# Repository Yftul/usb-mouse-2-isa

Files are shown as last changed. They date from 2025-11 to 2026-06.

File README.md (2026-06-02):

# usb-mouse-2-isa

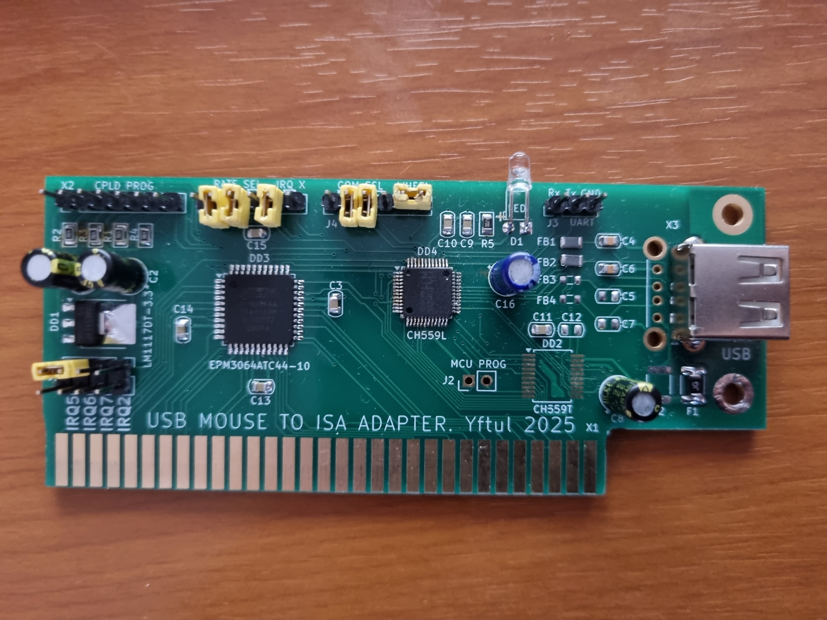
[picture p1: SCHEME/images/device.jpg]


**Проект / Project**
Подключение современной USB-мыши к старым ПК, ожидающим COM мышь.
Connect a modern USB mouse to an old PC expecting a COM mouse.

---

## Описание / Description

Проект `usb-mouse-2-isa` предназначен для реализации поддержки USB-мышей на ретро-компьютерах c ISA шиной.
The `usb-mouse-2-isa` project aims to provide USB mouse support on vintage computers with an ISA bus.

В основе — микроконтроллер и программируемая логика, которая:
At the core are a microcontroller and programmable logic that:

- принимает сигналы от USB-мыши / receive data from a USB mouse;
- преобразует в эмуляцию COM портовой мыши на ISA шине / converts into an emulation of a serial mouse on ISA bus.
- обеспечивает базовую функциональность: движение, нажатие кнопок, прокрутку / provide basic functionality: movement, button clicks, and wheel scrolling.

---

## Общие сведения / General info
Устройство устанавливается в ISA слот. Мышь подключается в USB разъём. При сбросе компьютера, включении и отключении мыши мигает светодиод активности VD1. Также он мигает, если работает драйвер выши и мышь проявляет какую-либо активность.
Перемычками COM SEL J4 можно выбрать COM порт COM1-COM4. При необходимости выбрать нестандартное прерывание, нужно установить перемычку IRQX J5 и выбрать необходимое прерывание IRQ2,5,6,7 установкой перемычки J1. Например:
оставив J4 1-2 3-4 и J5 5-6 без перемычек(open), устройство будет настроена на работу в качестве порта COM1 со стандартными port и IRQ 0x3F8/IRQ3. Если же установить все три перемычки, устройство будет откликаться на стандартный адрес COM4 0x2E8, но из-за установленного IRQX использовать один их IRQ2,5,6,7, выбранный перемычкой J1.
Все комбинации перемычек подписаны на плате.

Кроме того, можно выбрать поддержку колесика мыши, установив перемычку wheel J4 5-6. И уменьшить частоту передачи данных мыши по порту, установив перемычки Rate, где открытым(open) перемычкам соответсвует скорость передачи по умолчанию, устанавливая перемычки, замедляем скорость передачи до 4х раз.

--/

The device is installed into an ISA slot. The mouse is connected to the USB port. When the computer is reset, powered on, or when the mouse is plugged  or unplugged, the activity LED VD1 blinks. It also blinks when the mouse driver is running and the mouse generates any activity.

The COM SEL J4 jumpers allow selecting the COM port number (COM1–COM4). If a non‑standard interrupt is required, you must enable the IRQX jumper J5 and select the desired interrupt (IRQ2, 5, 6, or 7) using jumper J1. Examples:

 - if J4 1–2 and 3–4 are closed, and J5 5–6 is open, the device will be configured as COM1 with the standard port and IRQ (0x3F8 / IRQ3).
 - if all three jumpers are closed, the device will be at the standard COM4 address 0x2E8, but because IRQX is enabled, it will use one of IRQ2, 5, 6, or 7 selected by the jumper J1.

All possible jumpers combinations are written on the PCB.

Additionally, mouse wheel support can be enabled by closing the “wheel” jumper J4 5–6.  
You can also reduce the mouse data rate by configuring the Rate jumpers: the open (default) position corresponds to the normal data rate, and installing the jumpers reduces the rate by up to 4×.

## Структура репозитория / Repository structure

- `MCU/` — исходники микроконтроллера (C/ASM). / microcontroller firmware (C/ASM).
- `CPLD/` — исходники CPLD (VHDL). / CPLD logic design (VHDL).
- `SCHEME/` — схемы подключения, разводка. / schematics, wiring.
- `BIN/` — собранные прошивки. / compiled firmware.
- `README.md` — этот файл. / this README.
- `LICENSE` — лицензия проекта (GPL-3.0). / license file (GPL-3.0).

---

## Требования железа / Hardware requirements

- USB HID-мышь. / USB HID mouse.
- ПК с ISA-шиной и свободными ресурсами для подключения эмулируемого COM порта. / PC with ISA bus and enouth free resources to attach emulated COM port.
- Стандартный драйвер COM мыши / Standard serial mouse driver.

---

## Требования ПО / Software requirements

```bash
# 1. Сборка прошивки микроконтроллера / MCU firmware build
MCU: make clean && make

# 2. Для прошивки используется утилита WCHISPTool и кабель "USB-A - USB-A" / To flash MCU use WCHISPTool and cable "USB-A - USB-A"

# 3. Cинтез и прошивка CPLD / FPGA sinthesis and flash
Quartus 13 or earlier  + Altera byte blaster

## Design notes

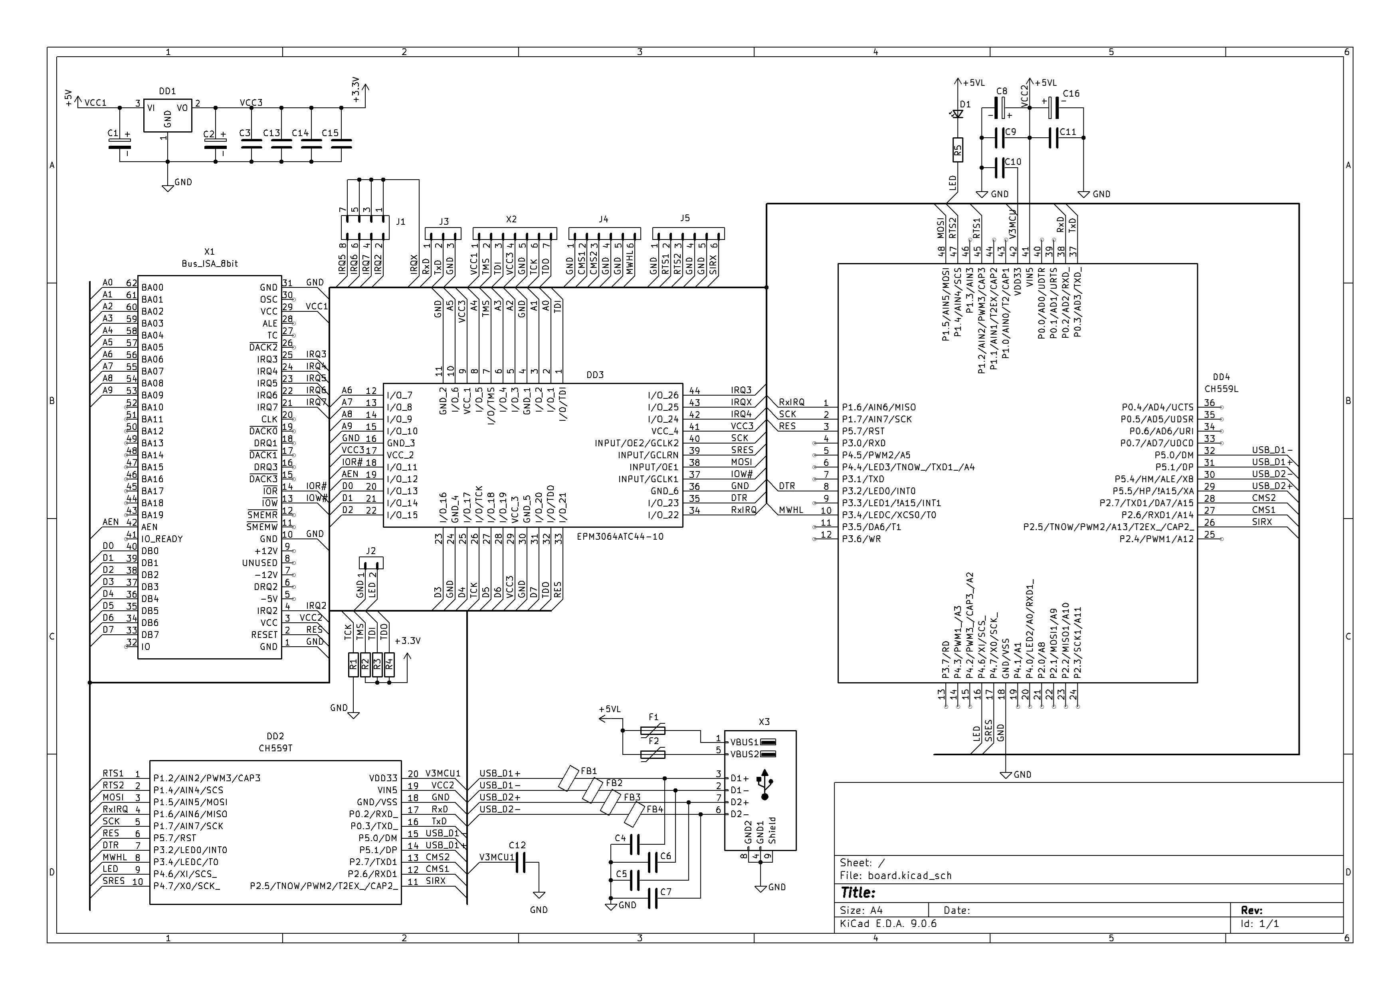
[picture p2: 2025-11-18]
SCHEME/images/scheme.jpg

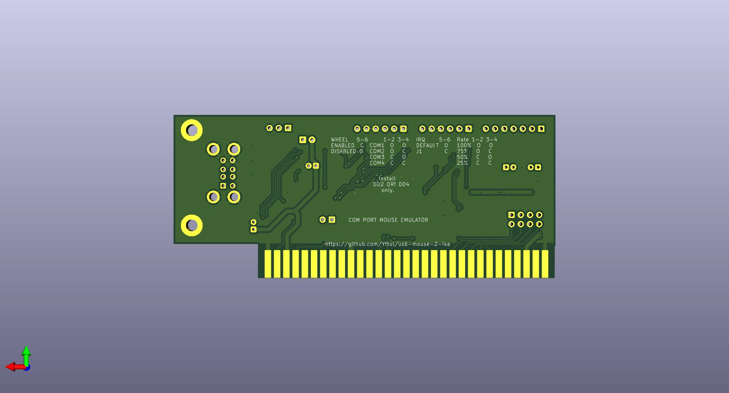
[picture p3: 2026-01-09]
SCHEME/images/board_b.jpg

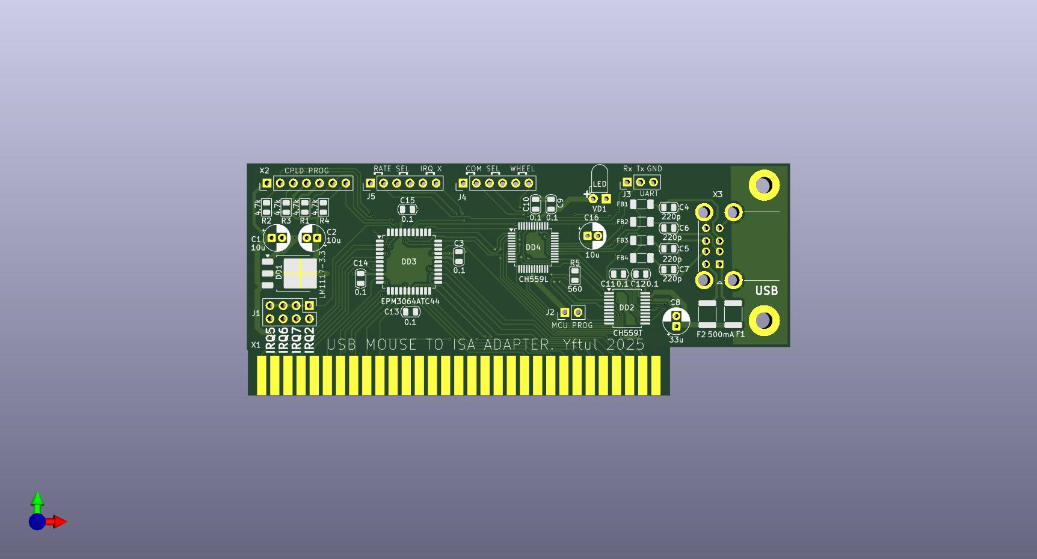
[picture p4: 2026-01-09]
SCHEME/images/board_f.jpg

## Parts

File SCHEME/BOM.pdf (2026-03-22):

Reference | Qty Value | Note
C1,C2,C16 | 3 | 10u | Electrolytic, THT D5.0mm P2.00mm. Can be 10uF to 50uF, 6.3V to 25V
C3,C9,C10,C11,C12,C13,C14,C15 | 8 | 0.1 | Ceramic 0805. Can be 0.068uF to 1uF
C4,C5,C6,C7 | 4 | 220p | Ceramic 0805. Can be 150...470pF
C8 | 1 | 33u | Electrolytic, THT D5.0mm P2.00mm. Can be 33uF to 100uF, 6.3V to 25V
DD1 | 1 | LM1117DT-3.3
DD2 | 1 | CH559T | Install DD2 or DD4 only
DD3 | 1 | EPM3064ATC44 | Can be replaced to ATF1504AS(need to recompile the firmware)
DD4 | 1 | CH559L | Install DD2 or DD4 only
F1 | 1 | 500mA | 1206
F2 | 1 | 500mA | 1206
FB1,FB2,FB3,FB4 | 4 | ~ | 1206 Ferrite bead. Can be replaced with resistor 0..10 Ohm
J1 | 1 | PINHD_2x4_Male
J2 | 1 | PINHD_1x2_Male
J3 | 1 | PINHD_1x3_Male
J4,J5 | 2 | PINHD_1x6_Male
R1,R2,R3,R4 | 4 | 4.7k | 0805. Can be 2…5.1K
R5 | 1 | 560 | 0805. Can be 330…680Ohm
VD1 | 1 | LED | THT 3.0 mm LED
X2 | 1 | PINHD_1x7_Male
X3 | 1 | USB_A_Stacked | Better 2 use single USB

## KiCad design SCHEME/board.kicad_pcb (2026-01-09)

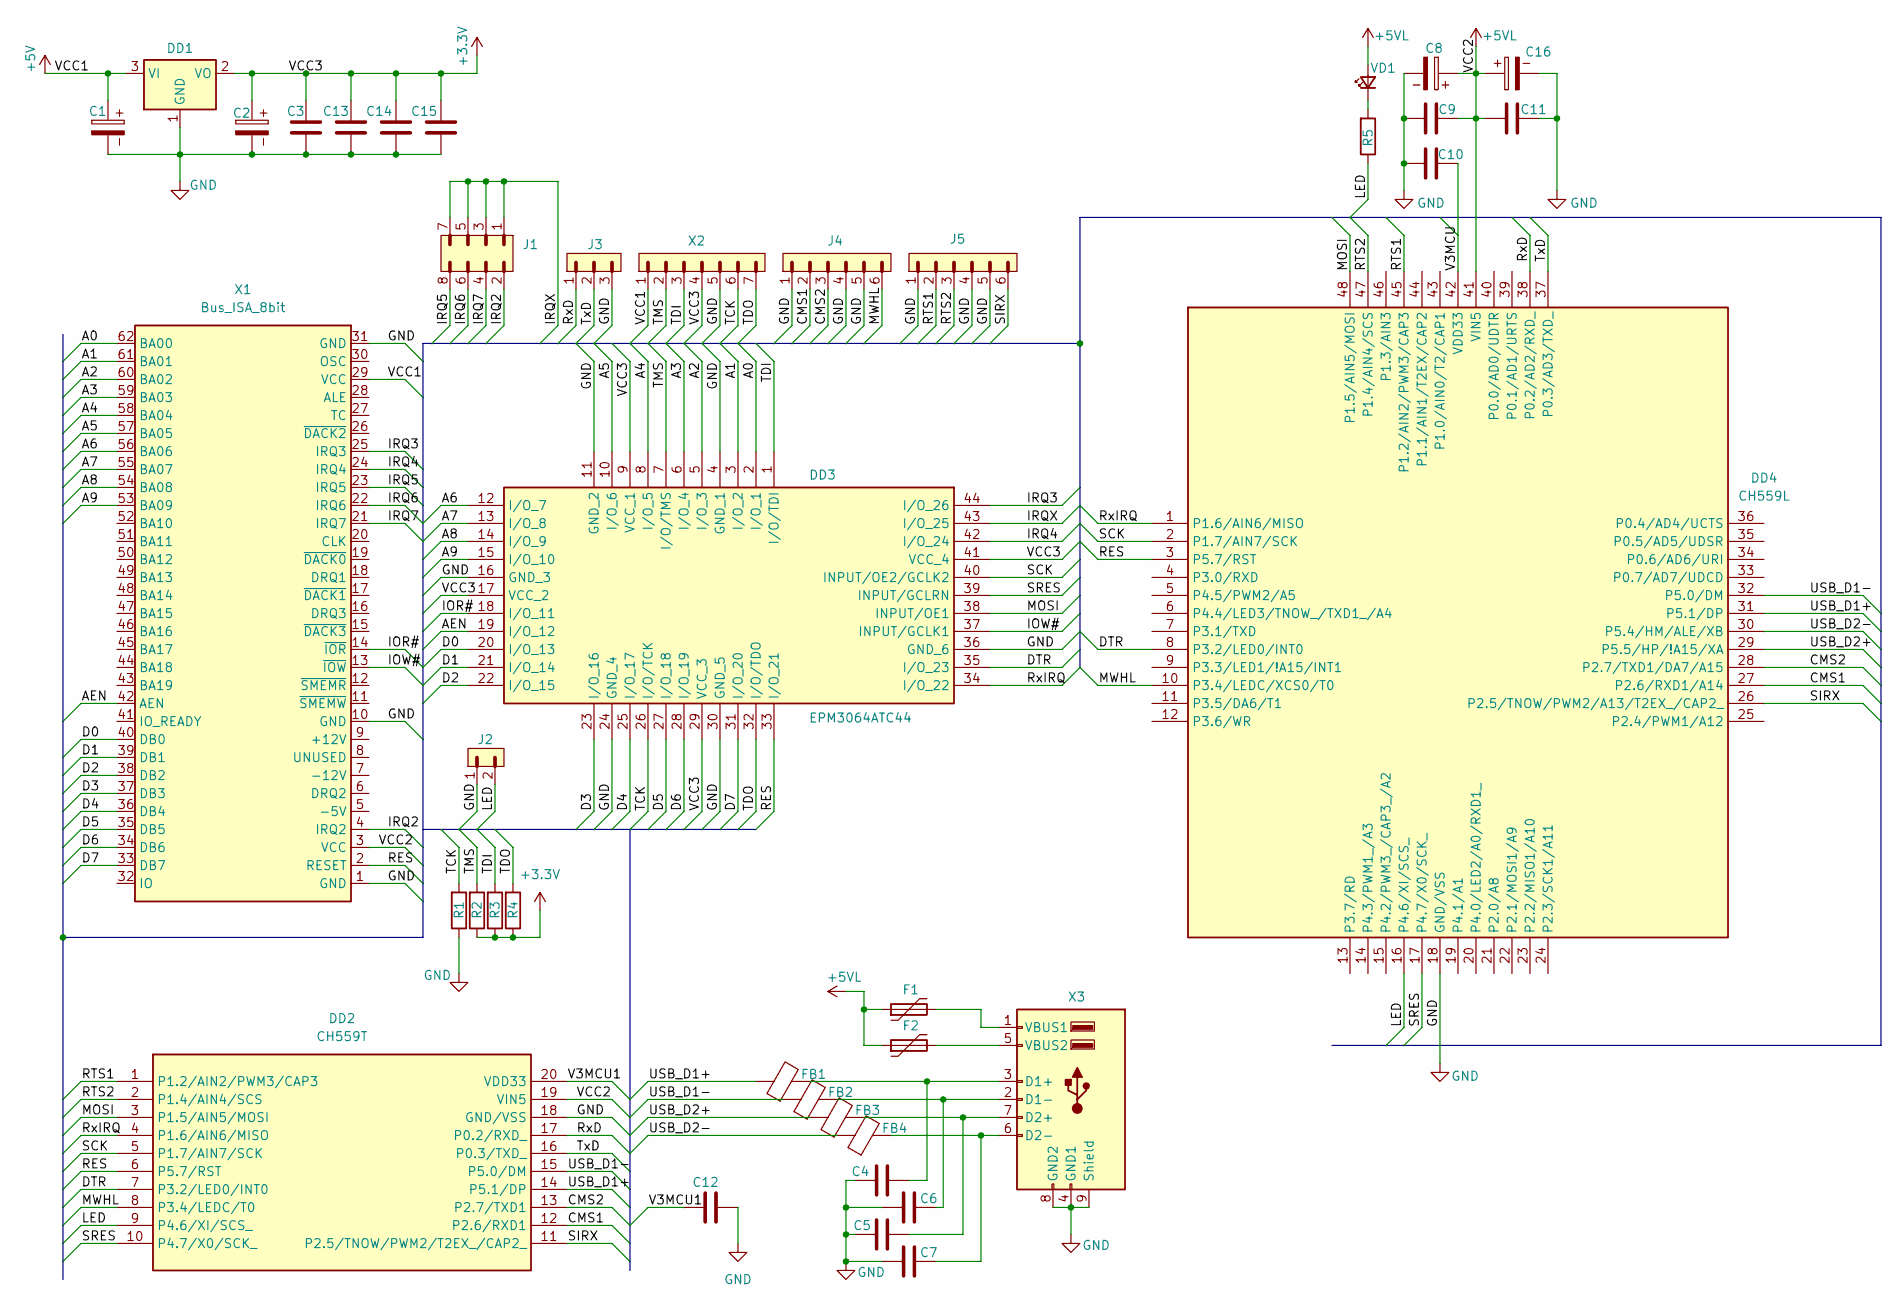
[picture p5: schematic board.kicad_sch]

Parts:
C1, C2, C16: 10u; CP_Radial_D5.0mm_P2.00mm
C3, C9, C10, C11, C12, C13, C14, C15: 0.1; C_0805_2012Metric
C4, C5, C6, C7: 220p; C_0805_2012Metric
C8: 33u; CP_Radial_D5.0mm_P2.00mm
DD1: LM1117DT-3.3; TO-252-3_TabPin2
DD2: CH559T; SSOP-20_5.3x7.2mm_P0.65mm; Manufacturer_Part_Number CH559L
DD3: EPM3064ATC44; TQFP-44_10x10mm_P0.8mm; Manufacturer_Part_Number EPM3032ATC44-4N; Mouser Part Number 989-EPM3032ATC44-4N
DD4: CH559L; LQFP-48_7x7mm_P0.5mm; Manufacturer_Part_Number CH559L
F1: Polyfuse_3A_15V; Fuse_1812_4532Metric; Part Number miniSMDC150F/24; JLCPCB ID C207070
F2: 500mA; Fuse_1812_4532Metric; Part Number miniSMDC150F/24; JLCPCB ID C207070
FB1, FB2, FB3, FB4: L_1206_3216Metric_Pad1.22x1.90mm_HandSolder
J1: PINHD_2x4_Male; PinHeader_2x04_P2.54mm_Vertical
J2: PINHD_1x2_Male; PinHeader_1x02_P2.54mm_Vertical
J3: PINHD_1x3_Male; PinHeader_1x03_P2.54mm_Vertical
J4, J5: PINHD_1x6_Male; PinHeader_1x06_P2.54mm_Vertical
R1, R2, R3, R4: 4.7k; R_0805_2012Metric
R5: 560; R_0805_2012Metric
VD1: LED; LED_D3.0mm_Horizontal_O1.27mm_Z2.0mm
X1: Bus_ISA_8bit; BUS_XT
X2: PINHD_1x7_Male; PinHeader_1x07_P2.54mm_Vertical
X3: USB_A_Stacked; USB_A_CUI_UJ2-ADH-TH_Horizontal_Stacked

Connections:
+3.3V: C2.1, C3.1, C13.1, C14.1, C15.1, DD1.2 (VO), DD3.9 (VCC_1), DD3.17 (VCC_2), DD3.29 (VCC_3), DD3.41 (VCC_4), R2.2, R3.2, R4.2, X2.4
+5V: C1.1, DD1.3 (VI), X1.29 (VCC), X2.1
+5VL: C8.1, C9.2, C11.1, C16.1, DD2.19 (VIN5), DD4.41 (VIN5), F1.1, F2.1, VD1.2 (A), X1.3 (VCC)
/A0: DD3.2 (I/O_1), X1.62 (BA00)
/A1: DD3.3 (I/O_2), X1.61 (BA01)
/A2: DD3.5 (I/O_3), X1.60 (BA02)
/A3: DD3.6 (I/O_4), X1.59 (BA03)
/A4: DD3.8 (I/O_5), X1.58 (BA04)
/A5: DD3.10 (I/O_6), X1.57 (BA05)
/A6: DD3.12 (I/O_7), X1.56 (BA06)
/A7: DD3.13 (I/O_8), X1.55 (BA07)
/A8: DD3.14 (I/O_9), X1.54 (BA08)
/A9: DD3.15 (I/O_10), X1.53 (BA09)
/AEN: DD3.19 (I/O_12), X1.42 (AEN)
/CMS1: DD2.12 (P2.6/RXD1), DD4.27 (P2.6/RXD1/A14), J4.2
/CMS2: DD2.13 (P2.7/TXD1), DD4.28 (P2.7/TXD1/DA7/A15), J4.3
/D0: DD3.20 (I/O_13), X1.40 (DB0)
/D1: DD3.21 (I/O_14), X1.39 (DB1)
/D2: DD3.22 (I/O_15), X1.38 (DB2)
/D3: DD3.23 (I/O_16), X1.37 (DB3)
/D4: DD3.25 (I/O_17), X1.36 (DB4)
/D5: DD3.27 (I/O_18), X1.35 (DB5)
/D6: DD3.28 (I/O_19), X1.34 (DB6)
/D7: DD3.31 (I/O_20), X1.33 (DB7)
/DTR: DD2.7 (P3.2/LED0/INT0), DD3.35 (I/O_23), DD4.8 (P3.2/LED0/INT0)
/IOR#: DD3.18 (I/O_11), X1.14 (~IOR)
/IOW#: DD3.37 (INPUT/GCLK1), X1.13 (~IOW)
/IRQ2: J1.2, X1.4 (IRQ2)
/IRQ3: DD3.44 (I/O_26), X1.25 (IRQ3)
/IRQ4: DD3.42 (I/O_24), X1.24 (IRQ4)
/IRQ5: J1.8, X1.23 (IRQ5)
/IRQ6: J1.6, X1.22 (IRQ6)
/IRQ7: J1.4, X1.21 (IRQ7)
/IRQX: DD3.43 (I/O_25), J1.1, J1.3, J1.5, J1.7
/LED: DD2.9 (P4.6/XI/SCS_), DD4.16 (P4.6/XI/SCS_), J2.2, R5.2
/MOSI: DD2.3 (P1.5/AIN5/MOSI), DD3.38 (INPUT/OE1), DD4.48 (P1.5/AIN5/MOSI)
/MWHL: DD2.8 (P3.4/LEDC/T0), DD4.10 (P3.4/LEDC/XCS0/T0), J4.6
/RES: DD2.6 (P5.7/RST), DD3.33 (I/O_21), DD4.3 (P5.7/RST), X1.2 (RESET)
/RTS1: DD2.1 (P1.2/AIN2/PWM3/CAP3), DD4.45 (P1.2/AIN2/PWM3/CAP3), J5.2
/RTS2: DD2.2 (P1.4/AIN4/SCS), DD4.47 (P1.4/AIN4/SCS), J5.3
/RxD: DD2.17 (P0.2/RXD_), DD4.38 (P0.2/AD2/RXD_), J3.1
/RxIRQ: DD2.4 (P1.6/AIN6/MISO), DD3.34 (I/O_22), DD4.1 (P1.6/AIN6/MISO)
/SCK: DD2.5 (P1.7/AIN7/SCK), DD3.40 (INPUT/OE2/GCLK2), DD4.2 (P1.7/AIN7/SCK)
/SIRX: DD2.11 (P2.5/TNOW/PWM2/T2EX_/CAP2_), DD4.26 (P2.5/TNOW/PWM2/A13/T2EX_/CAP2_), J5.6
/SRES: DD2.10 (P4.7/X0/SCK_), DD3.39 (INPUT/GCLRN), DD4.17 (P4.7/X0/SCK_)
/TCK: DD3.26 (I/O/TCK), R1.1, X2.6
/TDI: DD3.1 (I/O/TDI), R3.1, X2.3
/TDO: DD3.32 (I/O/TDO), R4.1, X2.7
/TMS: DD3.7 (I/O/TMS), R2.1, X2.2
/TxD: DD2.16 (P0.3/TXD_), DD4.37 (P0.3/AD3/TXD_), J3.2
/USB_D1+: DD2.14 (P5.1/DP), DD4.31 (P5.1/DP), FB1.1
/USB_D1-: DD2.15 (P5.0/DM), DD4.32 (P5.0/DM), FB2.1
/USB_D2+: DD4.29 (P5.5/HP/!A15/XA), FB3.1
/USB_D2-: DD4.30 (P5.4/HM/ALE/XB), FB4.1
/V3MCU: C10.2, DD4.42 (VDD33)
/V3MCU1: C12.1, DD2.20 (VDD33)
GND: C1.2, C2.2, C3.2, C4.1, C5.1, C6.1, C7.1, C8.2, C9.1, C10.1, C11.2, C12.2, C13.2, C14.2, C15.2, C16.2, DD1.1 (GND), DD2.18 (GND/VSS), DD3.4 (GND_1), DD3.11 (GND_2), DD3.16 (GND_3), DD3.24 (GND_4), DD3.30 (GND_5), DD3.36 (GND_6), DD4.18 (GND/VSS), J2.1, J3.3, J4.1, J4.4, J4.5, J5.1, J5.4, J5.5, R1.2, X1.1 (GND), X1.10 (GND), X1.31 (GND), X2.5, X3.4 (GND1), X3.8 (GND2), X3.9 (Shield)
unnamed: R5.1, VD1.1 (K)
unnamed: C4.2, FB1.2, X3.3 (D1+)
unnamed: C6.2, FB2.2, X3.2 (D1-)
unnamed: C5.2, FB3.2, X3.7 (D2+)
unnamed: C7.2, FB4.2, X3.6 (D2-)
unnamed: F1.2, X3.1 (VBUS1)
unnamed: F2.2, X3.5 (VBUS2)

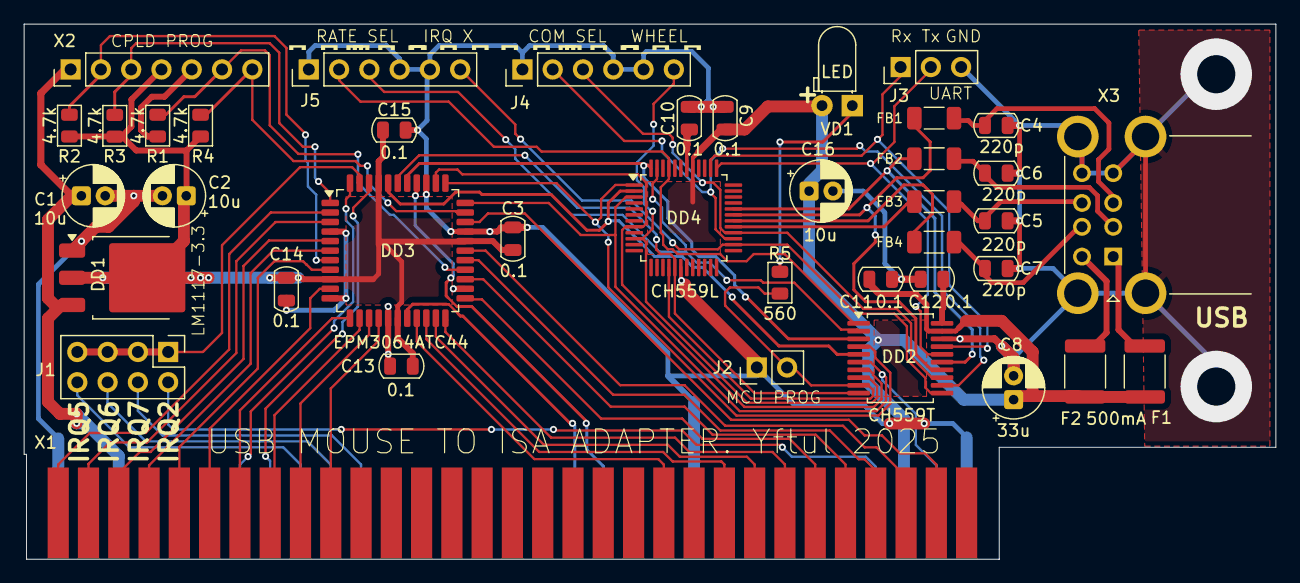
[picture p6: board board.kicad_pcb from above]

Board: 2 copper layers, 105.0 x 44.9 mm, 40 parts (0 on the bottom side), 64 nets.

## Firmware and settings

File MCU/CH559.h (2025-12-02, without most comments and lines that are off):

#define __CH559_H__
typedef unsigned char volatile __xdata    UINT8XV;
typedef unsigned char volatile __pdata    UINT8PV;
#include <compiler.h>
#include <stdint.h>
SFR(PSW,	0xD0);	// program status word
   SBIT(CY,	0xD0, 7);	// carry flag
   SBIT(AC,	0xD0, 6);	// auxiliary carry flag
   SBIT(F0,	0xD0, 5);	// bit addressable general purpose flag 0
   SBIT(RS1,	0xD0, 4);	// register R0-R7 bank selection high bit
   SBIT(RS0,	0xD0, 3);	// register R0-R7 bank selection low bit
#define MASK_PSW_RS       0x18      // bit mask of register R0-R7 bank selection
   SBIT(OV,	0xD0, 2);	// overflow flag
   SBIT(F1,	0xD0, 1);	// bit addressable general purpose flag 1
   SBIT(P,	0xD0, 0);	// ReadOnly: parity flag
SFR(ACC,	0xE0);	// accumulator
SFR(B,	0xF0);	// general purpose register B
SFR(SP,	0x81);	// stack pointer
SFR(DPL,	0x82);	// data pointer low
SFR(DPH,	0x83);	// data pointer high
SFR(SAFE_MOD,	0xA1);	// WriteOnly: writing safe mode
#define CHIP_ID           SAFE_MOD
SFR(GLOBAL_CFG,	0xB1);	// global config, Write@SafeMode
#define bBOOT_LOAD        0x20      // ReadOnly: boot loader status for discriminating BootLoader or Application: set 1 by power on reset, clear 0 by software reset
#define bSW_RESET         0x10      // software reset bit, auto clear by hardware
#define bCODE_WE          0x08      // enable flash-ROM (include code & data area) being program or erasing: 0=writing protect, 1=enable program and erase
#define bDATA_WE          0x04      // enable Data-Flash (flash-ROM data area) being program or erasing: 0=writing protect, 1=enable program and erase
#define bXIR_XSFR         0x02      // force MOVX_@R0/@R1 only for xSFR area: 0=MOVX_@R0/@R1 for standard xdata area inclde xRAM&xBUS&xSFR, 1=MOVX_@R0/@R1 for xSFR only
#define bWDOG_EN          0x01      // enable watch-dog reset if watch-dog timer overflow: 0=as timer only, 1=enable reset if timer overflow
SFR(PCON,	0x87);	// power control and reset flag
#define SMOD              0x80      // baud rate selection for UART0 mode 1/2/3: 0=slow(Fsys/128 @mode2, TF1/32 @mode1/3, no effect for TF2),
#define bRST_FLAG1        0x20      // ReadOnly: recent reset flag high bit
#define bRST_FLAG0        0x10      // ReadOnly: recent reset flag low bit
#define MASK_RST_FLAG     0x30      // ReadOnly: bit mask of recent reset flag
#define RST_FLAG_SW       0x00
#define RST_FLAG_POR      0x10
#define RST_FLAG_WDOG     0x20
#define RST_FLAG_PIN      0x30
#define GF1               0x08      // general purpose flag bit 1
#define GF0               0x04      // general purpose flag bit 0
#define PD                0x02      // power-down enable bit, auto clear by wake-up hardware
SFR(PLL_CFG,	0xB2);	// PLL clock config: lower 5 bits for PLL clock Fpll, upper 3 bits for USB 4x clock Fusb4x, Write@SafeMode
#define MASK_PLL_MULT     0x1F      // bit mask of PLL clock Fpll multiple
#define MASK_USB_4X_DIV   0xE0      // bit mask of USB 4x clock Fusb4x divisor, value 000b means 1000b
SFR(CLOCK_CFG,	0xB3);	// system clock config: lower 5 bits for system clock Fsys, Write@SafeMode
#define bOSC_EN_INT       0x80      // internal oscillator enable and original clock selection: 1=enable & select internal clock, 0=disable & select external clock
#define bOSC_EN_XT        0x40      // external oscillator enable, need quartz crystal or ceramic resonator between X1 and X2 pins
#define bWDOG_IF_TO       0x20      // ReadOnly: watch-dog timer overflow interrupt flag, cleared by reload watch-dog count or auto cleared when MCU enter interrupt routine
#define MASK_SYS_CK_DIV   0x1F      // bit mask of system clock Fsys divisor, value 00000b means 100000b
SFR(SLEEP_CTRL,	0xEA);	// sleep control, Write@SafeMode
#define bSLP_OFF_USB      0x80      // clock off for USB
#define bSLP_OFF_ADC      0x40      // clock off for ADC
#define bSLP_OFF_UART1    0x20      // clock off for UART1
#define bSLP_OFF_P1S1     0x10      // clock off for PWM1 / SPI1
#define bSLP_OFF_SPI0     0x08      // clock off for SPI0
#define bSLP_OFF_TMR3     0x04      // clock off for timer3
#define bSLP_OFF_LED      0x02      // clock off for LED
#define bSLP_OFF_XRAM     0x01      // clock off for xRAM
SFR(WAKE_CTRL,	0xEB);	// wake-up control, Write@SafeMode
#define bWAK_BY_USB       0x80      // enable wake-up by USB event
#define bWAK_RXD1_LO      0x40      // enable wake-up by RXD1 low level
#define bWAK_P1_5_LO      0x20      // enable wake-up by pin P1.5 low level
#define bWAK_P1_4_LO      0x10      // enable wake-up by pin P1.4 low level
#define bWAK_P0_3_LO      0x08      // enable wake-up by pin P0.3 low level
#define bWAK_CAP3_LO      0x04      // enable wake-up by CAP3 low level
#define bWAK_P3_2E_3L     0x02      // enable wake-up by pin P3.2 (INT0) edge or pin P3.3 (INT1) low level
#define bWAK_RXD0_LO      0x01      // enable wake-up by RXD0 low level
SFR(RESET_KEEP,	0xFE);	// value keeper during reset
SFR(WDOG_COUNT,	0xFF);	// watch-dog count, count by clock frequency Fsys/262144
SFR(IE,	0xA8);	// interrupt enable
   SBIT(EA,	0xA8, 7);	// enable global interrupts: 0=disable, 1=enable if E_DIS=0
   SBIT(E_DIS,	0xA8, 6);	// disable global interrupts, intend to inhibit interrupt during some flash-ROM operation: 0=enable if EA=1, 1=disable
   SBIT(ET2,	0xA8, 5);	// enable timer2 interrupt
   SBIT(ES,	0xA8, 4);	// enable UART0 interrupt
   SBIT(ET1,	0xA8, 3);	// enable timer1 interrupt
   SBIT(EX1,	0xA8, 2);	// enable external interrupt INT1
   SBIT(ET0,	0xA8, 1);	// enable timer0 interrupt
   SBIT(EX0,	0xA8, 0);	// enable external interrupt INT0 or LED interrupt
SFR(IP,	0xB8);	// interrupt priority and current priority
   SBIT(PH_FLAG,	0xB8, 7);	// ReadOnly: high level priority action flag
   SBIT(PL_FLAG,	0xB8, 6);	// ReadOnly: low level priority action flag
   SBIT(PT2,	0xB8, 5);	// timer2 interrupt priority level
   SBIT(PS,	0xB8, 4);	// UART0 interrupt priority level
   SBIT(PT1,	0xB8, 3);	// timer1 interrupt priority level
   SBIT(PX1,	0xB8, 2);	// external interrupt INT1 priority level
   SBIT(PT0,	0xB8, 1);	// timer0 interrupt priority level
   SBIT(PX0,	0xB8, 0);	// external interrupt INT0 priority level
SFR(IE_EX,	0xE8);	// extend interrupt enable
   SBIT(IE_WDOG,	0xE8, 7);	// enable watch-dog timer interrupt
   SBIT(IE_GPIO,	0xE8, 6);	// enable GPIO input interrupt
   SBIT(IE_PWM1,	0xE8, 5);	// enable PWM1 interrupt
   SBIT(IE_UART1,	0xE8, 4);	// enable UART1 interrupt
   SBIT(IE_ADC,	0xE8, 3);	// enable ADC interrupt
   SBIT(IE_USB,	0xE8, 2);	// enable USB interrupt
   SBIT(IE_TMR3,	0xE8, 1);	// enable timer3 interrupt
   SBIT(IE_SPI0,	0xE8, 0);	// enable SPI0 interrupt
SFR(IP_EX,	0xE9);	// extend interrupt priority
#define bIP_LEVEL         0x80      // ReadOnly: current interrupt nested level: 0=no interrupt or two levels, 1=one level
#define bIP_GPIO          0x40      // GPIO input interrupt priority level
#define bIP_PWM1          0x20      // PWM1 interrupt priority level
#define bIP_UART1         0x10      // UART1 interrupt priority level
#define bIP_ADC           0x08      // ADC interrupt priority level
#define bIP_USB           0x04      // USB interrupt priority level
#define bIP_TMR3          0x02      // timer3 interrupt priority level
#define bIP_SPI0          0x01      // SPI0 interrupt priority level
SFR(GPIO_IE,	0xCF);	// GPIO interrupt enable
#define bIE_IO_EDGE       0x80      // enable GPIO edge interrupt: 0=low/high level, 1=falling/rising edge
#define bIE_RXD1_LO       0x40      // enable interrupt by RXD1 low level / falling edge
#define bIE_P5_5_HI       0x20      // enable interrupt by pin P5.5 high level / rising edge
#define bIE_P1_4_LO       0x10      // enable interrupt by pin P1.4 low level / falling edge
#define bIE_P0_3_LO       0x08      // enable interrupt by pin P0.3 low level / falling edge
#define bIE_P5_7_HI       0x04      // enable interrupt by pin P5.7 (RST) high level / rising edge
#define bIE_P4_1_LO       0x02      // enable interrupt by pin P4.1 low level / falling edge
#define bIE_RXD0_LO       0x01      // enable interrupt by RXD0 low level / falling edge
SFR16(ROM_ADDR,	0x84);	// address for flash-ROM, little-endian
SFR(ROM_ADDR_L,	0x84);	// address low byte for flash-ROM
SFR(ROM_ADDR_H,	0x85);	// address high byte for flash-ROM
SFR16(ROM_DATA,	0x8E);	// data for flash-ROM writing, little-endian
SFR(ROM_DATA_L,	0x8E);	// data low byte for flash-ROM writing
SFR(ROM_DATA_H,	0x8F);	// data high byte for flash-ROM writing
SFR(ROM_CTRL,	0x86);	// WriteOnly: flash-ROM control
#define ROM_CMD_PROG      0x9A      // WriteOnly: flash-ROM word program operation command, for changing some ROM bit of a word from 1 to 0
#define ROM_CMD_ERASE     0xA6      // WriteOnly: flash-ROM sector erase operation command, for changing all ROM bit of 1KBytes from 0 to 1
#define ROM_STATUS        ROM_CTRL
#define bROM_ADDR_OK      0x40      // ReadOnly: flash-ROM operation address valid flag, can be reviewed before or after operation: 0=invalid parameter, 1=address valid
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

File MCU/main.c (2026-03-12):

/******************************************************************************
 * Project : USB-to-ISA Mouse Adapter — Replica
 * File    : main.c
 * Author  : Pyshchev Alexander aka Yftul
 * License : GPL-3.0
 *
 * Description :
 *     Firmware module for microcontroller side of USB-to-ISA adapter.
 *     Handles USB mouse communication, event parsing, buffering, and
 *     translation into ISA bus signals understood by legacy hardware.
 *
 * Notes :
 *     - Designed for embedded 8-bit MCU (e.g., ch559).
 *     - Uses hardware USB host and simple state machine for
 *       compatibility and low latency.
 ******************************************************************************/
#include <stdbool.h>
#include <stdint.h>
#include <stdio.h>
#include <string.h>
#include "CH559.h"
#include "util.h"
#include "USBHost.h"

//===========================================================================
// Общие определения и константы
//===========================================================================
// Не работает UART по прерыванию
// ToDo: починить
#define UART_fixed 0

#pragma disable_warning 126 /* Убирает назойливое предупреждение о недоступном коде */
                            /* связанном с передачей констант в SPI_SEND_PACKET */

#define UART_BAUDRATE  115200UL

#define MS_RX_BUF_SIZE 16      /* Размер приёмного буфера событй hid устройства,
                                * реально используется 4 байта
                                */
#define SPI_TX_BUFFER_SIZE 255 /* Размер буфера передачи SPI */
#define UART_TX_BUF_SIZE   128 /* Размер буфера передачи UART */
#define UART_TX_MASK       (UART_TX_BUF_SIZE - 1)

#define UART_RX_BUF_SIZE   16 /* Размер буфера приёма UART */
#define UART_RX_MASK       (UART_RX_BUF_SIZE - 1)

#define TIMER0_CONST (65536-4000) /* Период вызова прерывания 1 мс */
#define LED_CONST (64000) /* Длительность послесвечения светодиода (16 мс) */
#define TIMER2_RELOAD_FAST   (65536 - 100) /* Период вызова прерывания 25 мкс */
#define TIMER2_RELOAD_SLOW   (65536 - 400) /* Период вызова прерывания 100 мкс */

#define CRITICAL_SECTION(code_block) \
    do { \
        uint8_t _ea_state = EA; \
        EA = 0; \
        code_block \
        EA = _ea_state; \
    } while(0)

#define GLUE(a, b)      a##b
#define GLUE3(a, b, c)  a##b##c
#define _BV(bit)        (1U << (bit))

typedef enum {
    SELECT_COM1 = 0,
    SELECT_COM2 = 1,
    SELECT_COM3 = 2,
    SELECT_COM4 = 3,
} com_select_t;

typedef enum {
    PS2_SAMPLES_PER_SEC_10 = 10,
    PS2_SAMPLES_PER_SEC_20 = 20,
    PS2_SAMPLES_PER_SEC_40 = 40,
    PS2_SAMPLES_PER_SEC_60 = 60,
    PS2_SAMPLES_PER_SEC_80 = 80,
    PS2_SAMPLES_PER_SEC_100 = 100,
    PS2_SAMPLES_PER_SEC_200 = 200,
} data_rate_t;

#define PS2_SAMPLES_PER_SEC_UFAST   PS2_SAMPLES_PER_SEC_100
#define PS2_SAMPLES_PER_SEC_FAST    PS2_SAMPLES_PER_SEC_80
#define PS2_SAMPLES_PER_SEC_MID     PS2_SAMPLES_PER_SEC_40
#define PS2_SAMPLES_PER_SEC_SLOW    PS2_SAMPLES_PER_SEC_20

//===========================================================================
// Примитивы для работы с портами ch559
//===========================================================================
enum pin_mode {
    PIN_MODE_INPUT = 0,
    PIN_MODE_INPUT_PULLUP = 1,
    PIN_MODE_OUTPUT = 2,
    PIN_MODE_OUTPUT_OPEN_DRAIN = 3,
    PIN_MODE_OUTPUT_OPEN_DRAIN_2CLK = 4,
    PIN_MODE_INPUT_OUTPUT_PULLUP = 5,
    PIN_MODE_INPUT_OUTPUT_PULLUP_2CLK = 6,
};

#define _PORT_IN_P0   P0
#define _PORT_IN_P1   P1
#define _PORT_IN_P2   P2
#define _PORT_IN_P3   P3
#define _PORT_IN_P4   P4_IN
#define _PORT_IN_P5   P5

#define _PORT_OUT_P0   P0
#define _PORT_OUT_P1   P1
#define _PORT_OUT_P2   P2
#define _PORT_OUT_P3   P3
#define _PORT_OUT_P4   P4_OUT
#define _PORT_OUT_P5   P5

#define _PORT_OC_P0   _OC
#define _PORT_OC_P1   _OC
#define _PORT_OC_P2   _OC
#define _PORT_OC_P3   _OC

#ifndef bP4_OC
#define bP4_OC 0
#endif

#define PORT_OUT(x)    GLUE(_PORT_OUT_, x) /* ожидаем: P1 -> P1, P4 - > P4_OUT */
#define PORT_IN(x)     GLUE(_PORT_IN_, x)  /* ожидаем: P1 -> P1, P4 - > P4_IN */
#define PORT_DIR(x)    GLUE(x, _DIR)  /* ожидаем: P1 -> P1_DIR */
#define PORT_PU(x)     GLUE(x, _PU) /* ожидаем: P1 -> P1_PU, P4 - > P4_PU */
#define PORT_OC(x)     GLUE3(b, x, _OC)  /* ожидаем: P1 -> bP1_OC, bP4 -> bP4_OC */

#define pinMode(port, pin, mode)\
do {\
    if ((mode) == PIN_MODE_INPUT) {\
        PORT_CFG &= ~PORT_OC(port);\
        PORT_DIR(port) &= ~(1 << (pin));\
        PORT_PU(port) &= ~(1 << (pin));\
    } else if ((mode) == PIN_MODE_INPUT_PULLUP) {\
        PORT_CFG &= ~PORT_OC(port);\
        PORT_DIR(port) &= ~(1 << (pin));\
        PORT_PU(port) |=  (1 << (pin));\
    } else if ((mode) == PIN_MODE_OUTPUT) {\
        PORT_CFG &= ~PORT_OC(port);\
        PORT_DIR(port) |=  (1 << (pin));\
        /*PORT_PU(port) not used*/\
    } else if ((mode) == PIN_MODE_OUTPUT_OPEN_DRAIN) {\
        PORT_CFG |= PORT_OC(port);\
        PORT_DIR(port) &= ~(1 << (pin));\
        PORT_PU(port) &= ~(1 << (pin));\
    } else if ((mode) == PIN_MODE_OUTPUT_OPEN_DRAIN_2CLK) {\
        PORT_CFG |= PORT_OC(port);\
        PORT_DIR(port) |=  (1 << (pin));\
        PORT_PU(port) &= ~(1 << (pin));\
    } else if ((mode) == PIN_MODE_INPUT_OUTPUT_PULLUP) {\
        PORT_CFG |= PORT_OC(port);\
        PORT_DIR(port) &= ~(1 << (pin));\
        PORT_PU(port) |=  (1 << (pin));\
    } else if ((mode) == PIN_MODE_INPUT_OUTPUT_PULLUP_2CLK) {\
        PORT_CFG |= PORT_OC(port);\
        PORT_DIR(port) |=  (1 << (pin));\
        PORT_PU(port) |=  (1 << (pin));\
    }\
} while (0)

//===========================================================================
// Определение функционала ножек процессора.
//===========================================================================
#define SPI_RESOUT_PORT   P4 /* P4.7 HW RESET */
#define SPI_RESOUT_PIN    7
#define SPI_MOSI_PORT     P1 /* P1.5 HW MOSI */
#define SPI_MOSI_PIN      5
#define SPI_SCK_PORT      P1 /* P1.7 HW SCK */
#define SPI_SCK_PIN       7

#define DTR_PORT          P3 /* P3.2 INT0 */
#define DTR_PIN           2

#if USE_DEVBOARD
#define LED_PORT          P1
#define LED_PIN           4
#else
#define LED_PORT          P4 /* Один вывод с PRG */
#define LED_PIN           6
#endif

#define PRG_PORT          P4
#define PRG_PIN           6

#define COM_SEL1_PORT     P2
#define COM_SEL1_PIN      6
#define COM_SEL2_PORT     P2
#define COM_SEL2_PIN      7

#define WHEEL_SEL_PORT    P3
#define WHEEL_SEL_PIN     4

#define IRQX_SEL_PORT     P2
#define IRQX_SEL_PIN      5

#define RATE_SEL1_PORT    P1
#define RATE_SEL1_PIN     2
#define RATE_SEL2_PORT    P1
#define RATE_SEL2_PIN     4

#define RxIRQ_PORT        P1
#define RxIRQ_PIN         6

#define USE_IRQ3          0
#define USE_IRQX          1
#define USE_IRQ4          2

#define RxD_PORT          P0
#define RxD_PIN           2
#define TxD_PORT          P0
#define TxD_PIN           3

//===========================================================================
// Данные от CPLD
//===========================================================================
// 1 - не готовность приема символа, 0 - готовность
#if USE_DEVBOARD // Не ждём подтверждения приема
#define not_rdy_2rcv() (0)
#else
#define not_rdy_2rcv() (PORT_IN(RxIRQ_PORT) & _BV(RxIRQ_PIN))
#endif

#define get_mouse_power_state() (PORT_IN(DTR_PORT) & _BV(DTR_PIN))

//===========================================================================
// Программый SPI для связи с CPLD
//===========================================================================
#define spi_mosi_high()    (PORT_OUT(SPI_MOSI_PORT) |= _BV(SPI_MOSI_PIN))
#define spi_mosi_low()     (PORT_OUT(SPI_MOSI_PORT) &= ~_BV(SPI_MOSI_PIN))
#define spi_sck_high()     (PORT_OUT(SPI_SCK_PORT) |= _BV(SPI_SCK_PIN))
#define spi_sck_low()      (PORT_OUT(SPI_SCK_PORT) &= ~_BV(SPI_SCK_PIN))
#define spi_reset_high()   (PORT_OUT(SPI_RESOUT_PORT) |= _BV(SPI_RESOUT_PIN))
#define spi_reset_low()    (PORT_OUT(SPI_RESOUT_PORT) &= ~_BV(SPI_RESOUT_PIN))

#define spi_timer_stop()  do { TR2 = 0; } while(0)

#define spi_timer_fast()  do { \
    TR2 = 0; \
    RCAP2H = (uint8_t)((TIMER2_RELOAD_FAST >> 8) & 0xFF); \
    RCAP2L = (uint8_t)(TIMER2_RELOAD_FAST & 0xFF); \
    TH2 = RCAP2H; TL2 = RCAP2L; \
    TR2 = 1; \
} while(0)

#define spi_timer_slow()  do { \
    TR2 = 0; \
    RCAP2H = (uint8_t)((TIMER2_RELOAD_SLOW >> 8) & 0xFF); \
    RCAP2L = (uint8_t)(TIMER2_RELOAD_SLOW & 0xFF); \
    TH2 = RCAP2H; TL2 = RCAP2L; \
    TR2 = 1; \
} while(0)

#define SPI_DELAY() do { __asm__("nop"); __asm__("nop"); \
    __asm__("nop"); __asm__("nop"); } while(0)

#define SPI_SEND_BIT(bit_mask, tx_data) do { \
    spi_sck_low(); \
    SPI_DELAY(); \
    if ((tx_data) & (bit_mask)) spi_mosi_high(); else spi_mosi_low(); \
    SPI_DELAY(); \
    spi_sck_high(); \
    SPI_DELAY(); \
} while (0)

// Пакет из 7 бит с данными мыши
#define SPI_SEND_PACKET(tx_data) do { \
    SPI_SEND_BIT(0x40, (tx_data)); \
    SPI_SEND_BIT(0x20, (tx_data)); \
    SPI_SEND_BIT(0x10, (tx_data)); \
    SPI_SEND_BIT(0x08, (tx_data)); \
    SPI_SEND_BIT(0x04, (tx_data)); \
    SPI_SEND_BIT(0x02, (tx_data)); \
    SPI_SEND_BIT(0x01, (tx_data)); \
    spi_sck_low(); \
    spi_mosi_low(); \
} while (0)

#define SPI_RESET() do { spi_reset_high(); spi_reset_low(); } while(0)

//===========================================================================
// Светодиод
//===========================================================================
#if USE_DEVBOARD
#define led_on()        (PORT_OUT(LED_PORT) |= _BV(LED_PIN))
#define led_off()       (PORT_OUT(LED_PORT) &= ~_BV(LED_PIN))
#else
#define led_on()        (PORT_OUT(LED_PORT) &= ~_BV(LED_PIN))
#define led_off()       (PORT_OUT(LED_PORT) |= _BV(LED_PIN))
#endif

#define led_timer_stop()  do { T3_CTRL &= ~bT3_CNT_EN; } while(0)
#define led_timer_start() do { T3_CTRL |= bT3_CNT_EN; } while(0)

//===========================================================================
// Декларации функций
//===========================================================================
static inline void spi_send_config(uint8_t opt_com, uint8_t opt_irq);
extern FunctionReference runBootloader;

//===========================================================================
// Глобальные переменные
//===========================================================================
static uint8_t opt_com_settings;
static uint8_t opt_wheel_enabled;
static uint8_t opt_rate_settings;
static uint8_t opt_irq_settings;

static volatile uint8_t m_wheel;

static volatile uint8_t spi_tx_buf[SPI_TX_BUFFER_SIZE];
static volatile uint8_t spi_tx_buf_w;
static volatile uint8_t spi_tx_buf_r;
static volatile uint8_t spi_tx_buf_count;

static volatile uint8_t uart_tx_buf[UART_TX_BUF_SIZE];
static volatile uint8_t uart_tx_r;
static volatile uint8_t uart_tx_w;

static volatile uint8_t uart_rx_buf[UART_RX_BUF_SIZE];
static volatile uint8_t uart_rx_r;
static volatile uint8_t uart_rx_w;
static volatile uint8_t uart_rx_buf_count;

static volatile uint8_t mouse_start;      // Необходимо вывести приветствие мыши
static volatile uint8_t mouse_enabled;    // Мышь активна
static volatile uint8_t device_init;      // Произведена инициализация адресов/IRQ устройства
static volatile uint8_t allow_send_data;  // Флаг синхронизации передачи данных
static volatile uint8_t fatal_error;
static volatile uint8_t timer0_limit;

//===========================================================================
// Общие функции
//===========================================================================
// Отправить MCU в сон
static inline void mcu_sleep(void)
{
    // Не работает, вызывает проблемы со SPI
    // PCON |= PD;  // Power down mode
}

//===========================================================================
// Ограничение переменной значениями [min, max]
static inline int8_t clamp8(int16_t val, int8_t min, int8_t max)
{
    if (val < (int16_t)min) return min;
    if (val > (int16_t)max) return max;
    return (int8_t)val;
}

static inline int16_t clamp16(int32_t val, int16_t min, int16_t max)
{
    if (val < (int32_t)min) return min;
    if (val > (int32_t)max) return max;
    return (int16_t)val;
}

//===========================================================================
// Прерывания
//===========================================================================
// Выключилась линия RTS
static void int0_isr(void) __interrupt (INT_NO_INT0)
{
    mouse_enabled = get_mouse_power_state();
}

// Задается частота вывода сигнала мыши
static void timer0_isr(void) __interrupt (INT_NO_TMR0)
{
    static uint8_t cnt = 0;

    if (++cnt >= timer0_limit) {
        cnt = 0;
        allow_send_data = true;
    }
}

// Управление послесвечением светодиода
static void Timer3_ISR(void) __interrupt (INT_NO_TMR3)
{
    T3_STAT |= bT3_IF_END;
    led_off();
    led_timer_stop();
}

// Передача данных мыши в CPLD
static void Timer2_ISR(void) __interrupt (INT_NO_TMR2)
{
    uint8_t current_byte;
    TF2 = 0; // Не сбрасывается автоматически

    // Проверяем возможность передачи
    if (not_rdy_2rcv() && device_init) {
        // Медленно продолжаем проверять возможность передачи
        spi_timer_slow();
        return;
    }

    // Нечего передавать, останавливаемся
    if (!spi_tx_buf_count) {
        spi_timer_stop();
        return;
    }

    device_init = true;

    // Забираем байт из буфера
    current_byte = spi_tx_buf[spi_tx_buf_r];
    if (++spi_tx_buf_r == SPI_TX_BUFFER_SIZE) {
        spi_tx_buf_r = 0;
    }
    spi_tx_buf_count--;

    // Линейная передача без циклов
    SPI_SEND_PACKET(current_byte);

    // Управление таймером
    if (!spi_tx_buf_count) { // Нечего передавать, останавливаемся
        spi_timer_stop();
    } else {                 // Продолжаем передавать
        spi_timer_fast();
    }
}

// Обработка событий UART
static void uart_isr(void) __interrupt (INT_NO_UART0)
{
    uint8_t next;
    if (TI) {
        TI = 0;
        next = (uart_tx_r + 1) & UART_TX_MASK;
        if (next != uart_tx_w) {
            SBUF = uart_tx_buf[uart_tx_r];
            uart_tx_r = next;
        }
    }

    if (RI) {
        RI = 0;
        if (uart_rx_buf_count < UART_RX_BUF_SIZE) {
            uart_rx_buf[uart_rx_w] = SBUF;
            uart_rx_w = (uart_rx_w + 1) & UART_RX_MASK;
            uart_rx_buf_count++;
        }
    }
}

//===========================================================================
// Принимаем команды из UART
//===========================================================================
// putchar используется функцией printf
#if UART_fixed
int putchar(int c)
{
    uint8_t next;
    CRITICAL_SECTION(
        next = (uart_tx_w + 1) & UART_TX_MASK;
        if (next == uart_tx_r) { // Переполнение
            return -1;
        }

        uart_tx_buf[uart_tx_w] = c & 0xFF;
        if (uart_tx_w == uart_tx_r) {
            TI = 1;
        }
        uart_tx_w = next;
    );
    return c;
}
#else
int putchar(int c)
{
    while(!TI) ;
    TI = 0;
    SBUF = c & 0xFF;
    return c;
}
#endif
#if UART_fixed
// getchar может использоваться функцией scanf
int getchar(void)
{
    uint8_t c = 0;
    CRITICAL_SECTION(
        if (uart_rx_buf_count) {
            c = uart_rx_buf[uart_rx_r];
            uart_rx_r = (uart_rx_r + 1) & UART_RX_MASK;
            uart_rx_buf_count--;
        }
    );
    return c;
}
#else
int getchar(void)
{
    while(!RI) ;
    RI = 0;
    return SBUF;
}
#endif

// Переход в режим программирования(аналог замыканию пинов)
void processUart(void)
{
#if UART_fixed
    while(uart_rx_buf_count > 2) {
        if (getchar() == '~')
            if (getchar() == '~')
                if (getchar() == '~')
                    runBootloader();
    }
#endif
}

//===========================================================================
// Управление светодиодом
//===========================================================================
// Мигнуть светодиодом
void flash_led(void)
{
    led_on();
    led_timer_start();
}

//===========================================================================
// Soft SPI порт
//===========================================================================
// Инициализация Soft SPI
static inline void spi_init(void)
{
    CRITICAL_SECTION (
        spi_reset_high();
        delayUs(2);

        spi_tx_buf_w = 0;
        spi_tx_buf_r = 0;
        spi_tx_buf_count = 0;

        // CPLD сброшен, требуется передача байта конфигурации
        if (!device_init) {
            // Сбрасываем базовые настройки устройства
            spi_mosi_high();
            delayUs(1);
            spi_mosi_low();
            delayUs(2);
            // Инициализация порта и IRQ
            spi_send_config(opt_com_settings, opt_irq_settings);
        }
        spi_reset_low();
        delayUs(2);
    );

    // Ждём инициализацию устройства
    while (!device_init) {
        mcu_sleep();
    }
}

// Добавление значения в буфер передачи SPI
static void spi_send(uint8_t c)
{
    while (spi_tx_buf_count == SPI_TX_BUFFER_SIZE) {
        mcu_sleep();
    } ;

    CRITICAL_SECTION (
        spi_tx_buf[spi_tx_buf_w] = c;
        if (spi_tx_buf_count++ == 0)
            spi_timer_fast();
        if (++spi_tx_buf_w == SPI_TX_BUFFER_SIZE) {
            spi_tx_buf_w = 0;
        }
    );
}

// Отправка конфигурации устройства через SPI
static inline void spi_send_config(uint8_t opt_com, uint8_t opt_irq)
{
    uint8_t config_data = 0;
    config_data |= (opt_com & 0x03); // Base adress
    config_data |= (opt_irq == USE_IRQX) ? 0x4 : 0; // Не использовать стандартное IRQ

    spi_send(config_data);
}

// Отправка данных мыши через SPI
static inline void spi_m_send(int8_t x, int8_t y, int8_t z, uint8_t b)
{
    uint8_t left_b, right_b, middle_b;

    left_b = b & 1;
    right_b = (b >> 1) & 1;
    middle_b = (b >> 2) & 1;

    spi_send((1 << 6) | (left_b << 5) | (right_b << 4) |
             ((y & 0xC0) >> 4) | ((x & 0xC0) >> 6));
    spi_send(x & 0x3F);
    spi_send(y & 0x3F);

    // Данные с колесика посылаем только если установлен джампер
    if (m_wheel) {
        spi_send((middle_b << 4) | (z & 0x0F));
    }

    flash_led();
}

// Отправка приветствия мыши
static inline void send_mouse_id(void)
{
    // Имитация переходных процессов при включении
    delay(20);

    // Не передаем ID при кратковременных включениях
    if (!mouse_enabled) {
        return;
    }

    // Приветствие Logitech/Microsoft Plus
    spi_send(0x4D); // Сигнатура MS mouse "M"
    if (m_wheel) {
        spi_send(0x5A); // Сигнатура мыши с колёсиком "Z"
        spi_send(0x40); // Четырехбайтные пакеты
        spi_send(0x00); // Пустой пакет байт 2
        spi_send(0x00); // Пустой пакет байт 3
        spi_send(0x00); // Пустой пакет байт 4
    } else {
        spi_send(0x33); // Сигнатура 3х кнопочной мыши "3"
        spi_send(0x40); // Трёхбайтные пакеты
        spi_send(0x00); // Пустой пакет байт 2
        spi_send(0x00); // Пустой пакет байт 3
    }
}

//===========================================================================
// Чтение джамперов
//===========================================================================
static inline uint8_t readCOMsettings(void)
{
    const uint8_t com_table[4] = {
        SELECT_COM4, SELECT_COM3,
        SELECT_COM2, SELECT_COM1
    };
    uint8_t jumpers = (((PORT_IN(COM_SEL1_PORT) & _BV(COM_SEL1_PIN))?1:0) |
                       ((PORT_IN(COM_SEL2_PORT) & _BV(COM_SEL2_PIN))?2:0));

    return com_table[jumpers];
}

static inline bool readWheelsettings(void)
{
    return !(PORT_IN(WHEEL_SEL_PORT) & _BV(WHEEL_SEL_PIN));
}

static inline uint8_t readRatesettings(void)
{
    const uint8_t rate_table[4] = {
        PS2_SAMPLES_PER_SEC_SLOW, PS2_SAMPLES_PER_SEC_MID,
        PS2_SAMPLES_PER_SEC_FAST, PS2_SAMPLES_PER_SEC_UFAST
    };
    uint8_t jumpers = (((PORT_IN(RATE_SEL1_PORT) & _BV(RATE_SEL1_PIN))?1:0) |
                   ((PORT_IN(RATE_SEL2_PORT) & _BV(RATE_SEL2_PIN))?2:0));

    return rate_table[jumpers];
}

static inline uint8_t checkIRQ(uint8_t opt_com)
{
    if (!(PORT_IN(IRQX_SEL_PORT) & _BV(IRQX_SEL_PIN))) {
        return USE_IRQX;
    }
    if (opt_com == SELECT_COM1 || opt_com == SELECT_COM3) {
        return USE_IRQ4;
    }
    return USE_IRQ3;
}
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
int main(void)
{
    init();

    DEBUG_OUT("Ready\n");
    DEBUG_OUT("COM select: COM%d\n", opt_com_settings + 1);
    DEBUG_OUT("Wheel: %s\n", opt_wheel_enabled?"true":"false");
    DEBUG_OUT("Rate select: %d\n", opt_rate_settings);
    DEBUG_OUT("IRQ select: %c\n", opt_irq_settings?(opt_irq_settings==1?'X':'4'):'3');

    for (;;) {
        if (!fatal_error) {
            WDOG_COUNT = 0;
        }

        if (!mouse_enabled) { // Мышь выключена
            // Проверяем не включили ли мышь
            mouse_enabled = get_mouse_power_state();
            if (mouse_enabled) {
                // Мышь включили, нужно послать ID
                mouse_start = true;
                allow_send_data = true;
            }
        }

        processUart();

        do_process();

        if (fatal_error ||
               (!allow_send_data &&
                !spi_tx_buf_count)) {
            mcu_sleep();
        }
    }
}

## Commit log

2025-12-02 Workable version, knows issues: 1. Board not completely fit to isa slot, requires filing; 2. Too small too small seating areas for beads; 3. Looks, lines from CH559T are too long, workable only with 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
    [board.kicad_pcb, board.kicad_sch]
2025-12-03 Added nop to fix the issues with long wiring to ch559t; Updated readme.
    [main.c]
2025-12-04 Reverted wheel sign
2026-01-09 Updated board: 1. Reduced ISA slot; 2. Changed beads from 0805 to 1206; 3. General trace improvements.
    [board.kicad_pcb, board.kicad_sch]
2026-02-20 Fix compatibility issues of complex HID devices
    [main.c]
2026-03-22 Added BOM
